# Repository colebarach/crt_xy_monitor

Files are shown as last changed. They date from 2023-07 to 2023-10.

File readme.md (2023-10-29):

# CRT Vector Display Driver

## Overview

This project outlines the design of a driver circuit for a CRT screen. The tube used in this project is a 4" magnetic coil driven screen from a GE portable TV. No information could be found online about this tube, so the pinout of it and its corresponding flyback had to be reverse engineered. 

### Notes

This repository details the design and creation of an X-Y monitor. For details on generating X-Y signals to display, see the sister repository (https://github.com/colebarach/lib_xy_display).

## Tube Power Supply

To power the CRT, several kilovolts must be provided to accelerate the electron beam. This is typically provided by a flyback transformer. As mentioned previously, the tube used in this project came with a transformer.
To drive the flyback transformer, a sinusoidal AC signal is approximated using a square wave generated with a monostable multivibrator.
This approach is not efficient, but it is sufficient for the size of the tube and is relatively simple.

## Circuit Schematic
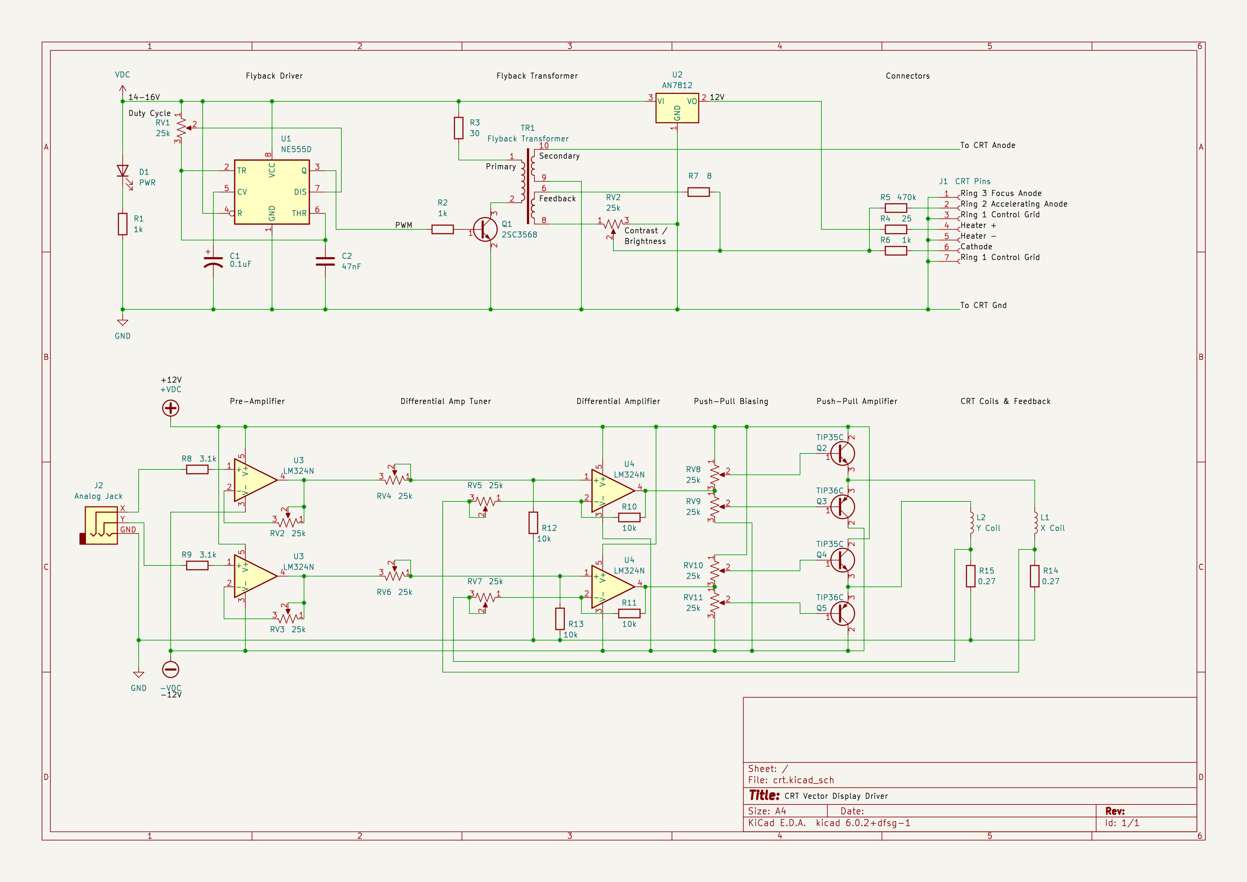
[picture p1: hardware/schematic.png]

*Datasheets are provided in the datasheets directory.

## Coil Driver
The coils of the CRT are responsible for the rendering.
Two signals are input to the driver, being the X and Y position of the beam, which range from -5V to 5V.
Each signal first runs through a pre-amplifier, which accomodates for the variety of signal generators used in testing.
The signals then go through negative feedback, unity gain, differential amplifiers, which receives feedback from the actual position of the beam.
Finally a set of push-pull amplifiers drives the high current required by the coils of the tube.
The position of the beam is proportional to the current drawn by each coil, but not the voltage of the coil. To accomodate for the effects of parasitic capacitance, this current is measured via a shunt resistor.
The voltage of this, proportional to the current, is used as the negative feedback for the differential amplifiers of the system.
- This design is derivative of one detailed in "The Secret Life of XY Monitors" by Jed Margolin. For a more in-depth explanation of its operation visit his work linked in the references.

## Generating X-Y Signals
Any device capable of generating two analog signals can be used with this driver, as long as the pre-amplifiers are capable of bringing it within range. The most accessible device which can do this is the audio output of a computer. The right and left channels can be mapped to X-Y (or vice versa) and images can be drawn. A tool known as "Rabiscoscopio" has been designed for this exact purpose (see Alex Porto's link below). Using Rabiscoscopio svg files can be converted to audio files and played. Several demos are also available for quick testing.

## References
- Cathode-Ray Tubes - Chuck DeVere (https://openlibrary.org/books/OL17878693M/Cathode-ray_tubes)
- Flyback Transformer Design Considerations for Efficiency and EMI - Texas Instruments (https://www.ti.com/seclit/ml/slup338/slup338.pdf)
- Operation of a Cathode Ray Tube - Georgia Institute of Technology
- Cathode Ray Tube Displays - MIT Radiation Laboratory (https://www.bunkerofdoom.com/lit/mitser/PREF22.PDF)
- Some Vector Generating Techniques for Cathode Ray Tube Display Systems - NASA Godoard Space Flight Center (https://ntrs.nasa.gov/api/citations/19670021973/downloads/19670021973.pdf)
- CRT Electron Beam Deflection with Microcontroller - Bob's Projects (https://bobparadiso.com/2015/04/13/crt-electron-beam-deflection-w-microcontroller/)
- The Secret Life of XY Monitors - Jed Margolin (http://www.jmargolin.com/xy/xymon.htm)
- Atari 19 and 25 Inch Color X-Y Display - Atari (https://www.andysarcade.net/personal/manualsother.htm)
- Wells-Gardner Quadrascan Color X-Y Display Service Manual - Atari - (https://archive.org/details/ArcadeGameManualTm183-2)
- Response of Electromagnetic Deflection for CRT Display - Hiroya Sano & Yoshihiro Tanada (https://core.ac.uk/download/pdf/12528813.pdf)
- Rabiscoscopio 2 - Alex Porto (https://dalpix.com/oscilloscope-drawing-everyone)
- Flyback Driver #1: Single Transistor Driver - Jozef Bogin Jr (http://boginjr.com/electronics/hv/flyback-driver-1/)
- Flyback Driver #2: NE555 Quasi-Resonant (http://boginjr.com/electronics/hv/flyback-driver-2/)
- Things to do: Drive a CRT - Jochen Kronjaeger (http://www.kronjaeger.com/hv-old/hv/do/crt/index.html)

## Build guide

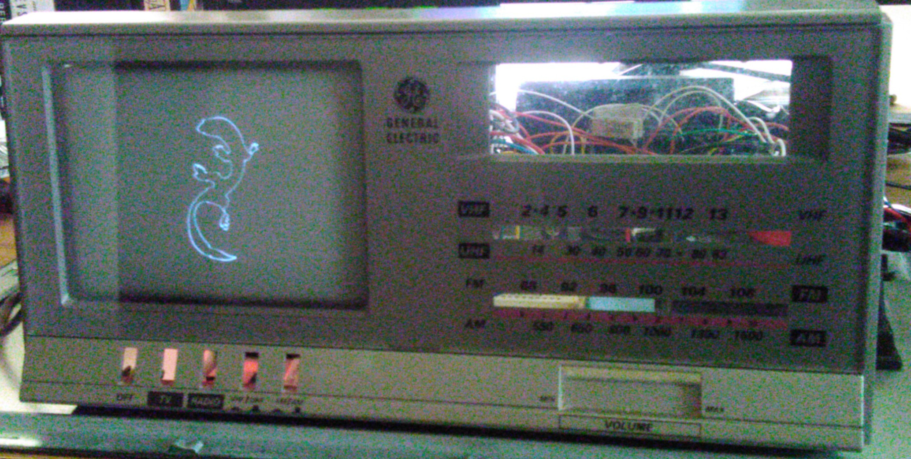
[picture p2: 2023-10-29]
tests/23.07.15 - Hardware Setup Screen.jpg

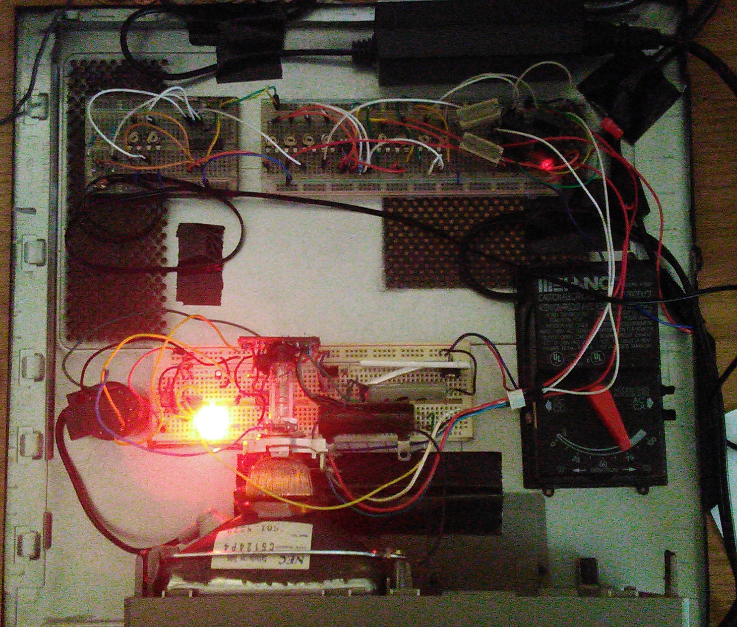
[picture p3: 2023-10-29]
tests/23.07.15 - Hardware Setup Top.jpg

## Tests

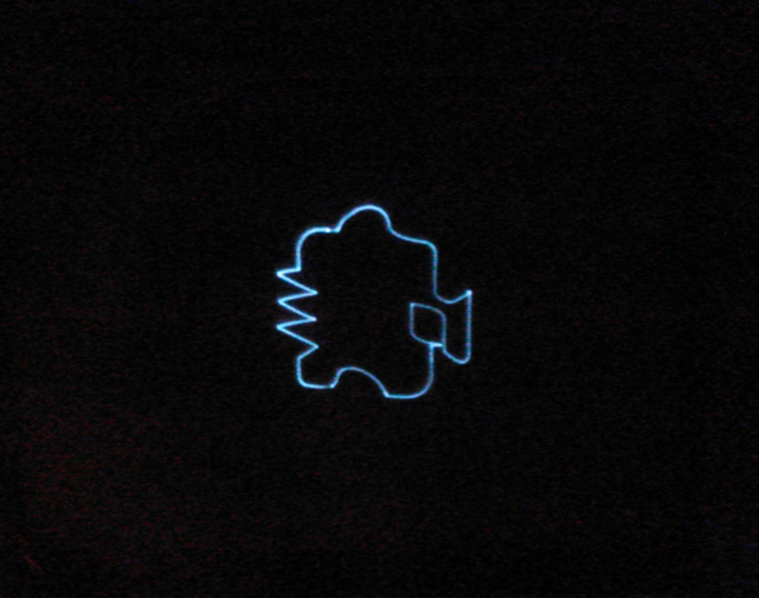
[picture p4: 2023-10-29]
tests/23.07.15 - Result Noisebridge.jpeg

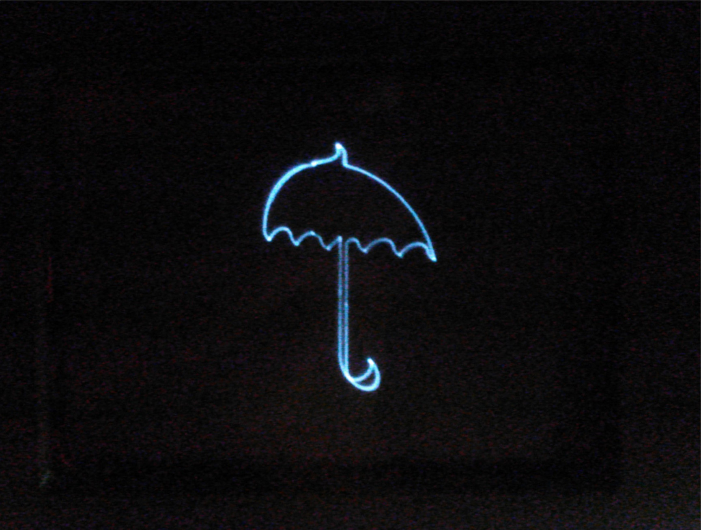
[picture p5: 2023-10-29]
tests/23.07.15 - Result Garoa.jpeg

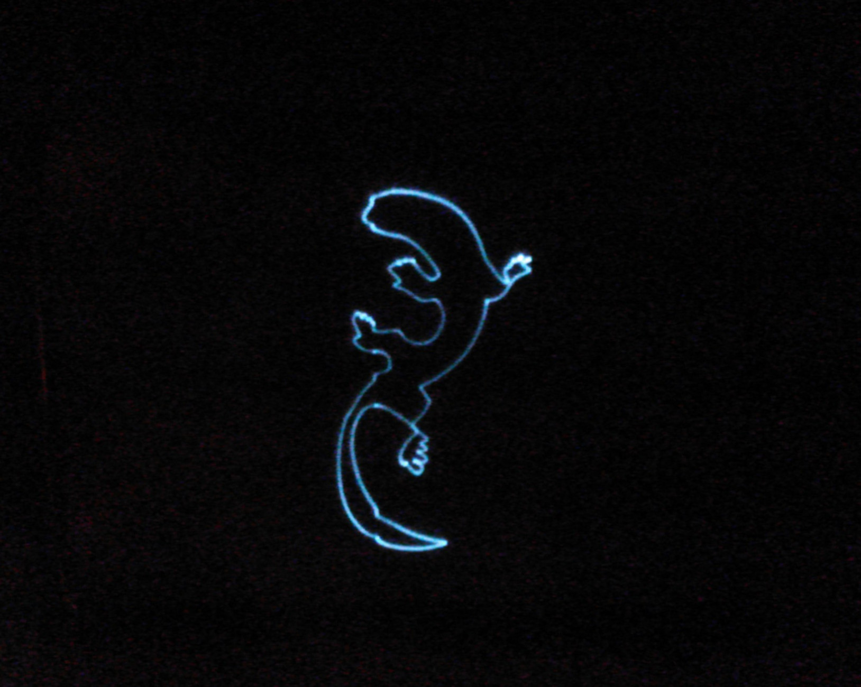
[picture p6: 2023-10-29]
tests/23.07.15 - Result Calango.jpeg

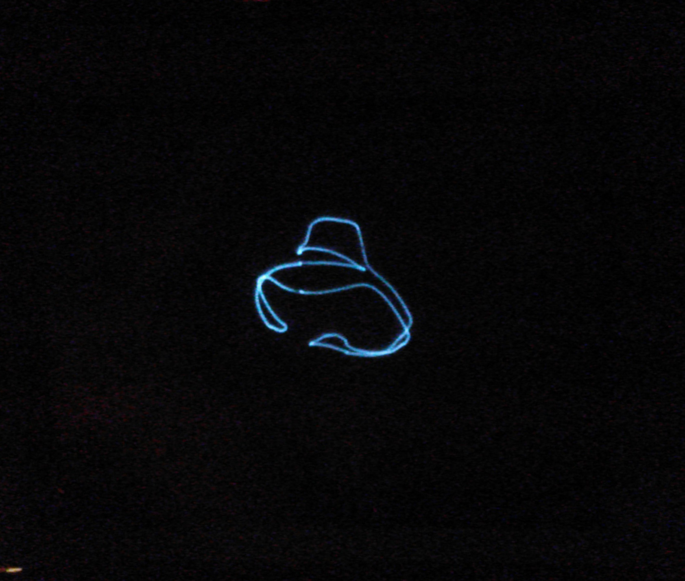
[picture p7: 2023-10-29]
tests/23.07.15 - Result Dumont.jpeg

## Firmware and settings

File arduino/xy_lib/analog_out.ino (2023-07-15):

#include <TimerOne.h>

const int xPin = 9;
const int yPin = 10;

int period = 64;

// 256
int distanceLookup[] =
{
  0,
  1501
};

void setup()
{
  Timer1.initialize(period);
  
  pinMode(xPin, OUTPUT);
  pinMode(yPin, OUTPUT);
}

void loop()
{
  demoSizeDelay2();
  
//  drawFontA(0, 0);
//  drawFontB(12, 0);
//  drawFontC(24, 0);
//  drawFontD(36, 0);
//  drawFontE(48, 0);
//  drawFontF(60, 0);
}

void drawFontNull(int x, int y)
{
  drawVector(x,   y);
  drawVector(x+8, y);
  drawVector(x+8, y+12);
  drawVector(x,   y+12);
  
  drawVector(x,   y);
  drawVector(x+8, y);
}

void drawFontA(int x, int y)
{
  drawVector(x,   y);
  drawVector(x+2, y+6);
  drawVector(x+6, y+6);
  drawVector(x+2, y+6);
  drawVector(x+4, y+12);
  drawVector(x+8, y);
}

void drawFontB(int x, int y)
{

  drawVector(x,   y);
  drawVector(x,   y+12);
  drawVector(x+8, y+12);
  drawVector(x+8, y+8);
  drawVector(x+6, y+6);
  drawVector(x,   y+6);
  drawVector(x+6, y+6);
  drawVector(x+8, y+4);
  drawVector(x+8, y);
  drawVector(x,   y);
}

void drawFontC(int x, int y)
{
  drawVector(x+8, y);
  drawVector(x+2, y);
  drawVector(x,   y+2);
  drawVector(x,   y+10);
  drawVector(x+2, y+12);
  drawVector(x+8, y+12);
}

void drawFontD(int x, int y)
{
  drawVector(x,   y);
  drawVector(x,   y+12);
  drawVector(x+6, y+12);
  drawVector(x+8, y+10);
  drawVector(x+8, y+2);
  drawVector(x+6, y);
  drawVector(x,   y);
}

void drawFontE(int x, int y)
{
  drawVector(x+8, y);
  drawVector(x,   y);
  drawVector(x,   y+6);
  drawVector(x+8, y+6);
  drawVector(x,   y+6);
  drawVector(x,   y+12);
  drawVector(x+8, y+12);
}

void drawFontF(int x, int y)
{
  drawVector(x,   y);
  drawVector(x,   y+6);
  drawVector(x+8, y+6);
  drawVector(x,   y+6);
  drawVector(x,   y+12);
  drawVector(x+8, y+12);
}

void drawPoint(int x, int y)
{
  Timer1.pwm(xPin, x, period);
  Timer1.pwm(yPin, y, period);
}

void drawVector(int x, int y)
{
  int distance = x;

  if(y > x) distance = y;

  delayMicroseconds(3200);

  Timer1.pwm(xPin, x, period);
  Timer1.pwm(yPin, y, period);
}

void demoSizeDelay()
{
  int step = 32;
  
  for(int x = step; x < 256; x += step)
  {
    drawVector(x,0);
    drawVector(x,x);
    drawVector(0,x);

    x += step;
    
    drawVector(0,x);
    drawVector(x,x);
    drawVector(x,0);
  }
}

void demoSizeDelay2()
{
  int step = 64;
  
  for(int x = step; x < 255; x += step)
  {
    drawVector(255-x,255);
    drawVector(255-x,255-x);
    drawVector(255,  255-x);

    x += step;
    
    drawVector(255,  255-x);
    drawVector(255-x,255-x);
    drawVector(255-x,255);
  }
}

void demoHilbertCurve(int depth)
{
  
}

void drawHilbertCurve(int x, int y, int rotation, int symmetry, int depth)
{
  if(depth == 0) return;
  
  // Scale LUT (1 / (2^x - 1))
  int scale = 255;
  if     (depth == 2) scale = 85;
  else if(depth == 3) scale = 36;
  else if(depth == 4) scale = 17;
  else if(depth == 5) scale = 8;
  else if(depth == 6) scale = 4;
  else if(depth == 7) scale = 2;
  else if(depth == 8) scale = 1;

  if(symmetry == 0)
  {
    if(rotation == 0)
    {
      drawHilbertCurve(x, y, 1, 1, depth-1);
      
      drawVector(x + scale + subscale, y);
      
      drawHilbertCurve(x, y, 0, 0, depth-1);
      
      drawVector(x + scale + subscale, y + scale + subscale);
      
      drawHilbertCurve(x, y + scale, 0, 0, depth-1);
      
      drawVector(x, y);
      
      drawHilbertCurve(x, y, 3, 1, depth-1);
    }
    else if(rotation == 1)
    {
      
    }
    else if(rotation == 2)
    {
      
    }
    else if(rotation == 3)
    {
      
    } 
  }
  else
  {
    if(rotation == 0)
    {
      
    }
    else if(rotation == 1)
    {
      
    }
    else if(rotation == 2)
    {
      
    }
    else if(rotation == 3)
    {
      
    }
  }
}

//
//void demoStar()
//{
//  Timer1.pwm(xPin, 127, period);
//  Timer1.pwm(yPin, 127, period);
//
//  delayMicroseconds(drawDelay);
//
//  Timer1.pwm(xPin, 255, period);
//  Timer1.pwm(yPin, 127, period);
//
//  delayMicroseconds(drawDelay);
//
//  Timer1.pwm(xPin, 127, period);
//  Timer1.pwm(yPin, 127, period);
//
//  delayMicroseconds(drawDelay);
//
//  Timer1.pwm(xPin, 225, period);
//  Timer1.pwm(yPin, 209, period);
//
//  delayMicroseconds(drawDelay);
//
//  Timer1.pwm(xPin, 127, period);
//  Timer1.pwm(yPin, 127, period);
//
//  delayMicroseconds(drawDelay);
//
//  Timer1.pwm(xPin, 149, period);
//  Timer1.pwm(yPin, 253, period);
//
//  delayMicroseconds(drawDelay);
//
//  Timer1.pwm(xPin, 127, period);
//  Timer1.pwm(yPin, 127, period);
//
//  delayMicroseconds(drawDelay);
//
//  Timer1.pwm(xPin, 63, period);
//  Timer1.pwm(yPin, 237, period);
//
//  delayMicroseconds(drawDelay);
//
//  Timer1.pwm(xPin, 127, period);
//  Timer1.pwm(yPin, 127, period);
//
//  delayMicroseconds(drawDelay);
//
//  Timer1.pwm(xPin, 7, period);
//  Timer1.pwm(yPin, 171, period);
//
//  delayMicroseconds(drawDelay);
//
//  Timer1.pwm(xPin, 127, period);
//  Timer1.pwm(yPin, 127, period);
//
//  delayMicroseconds(drawDelay);
//
//  Timer1.pwm(xPin, 7, period);
//  Timer1.pwm(yPin, 83, period);
//
//  delayMicroseconds(drawDelay);
//
//  Timer1.pwm(xPin, 127, period);
//  Timer1.pwm(yPin, 127, period);
//
//  delayMicroseconds(drawDelay);
//
//  Timer1.pwm(xPin, 63, period);
//  Timer1.pwm(yPin, 17, period);
//
//  delayMicroseconds(drawDelay);
//
//  Timer1.pwm(xPin, 127, period);
//  Timer1.pwm(yPin, 127, period);
//
//  delayMicroseconds(drawDelay);
//
//  Timer1.pwm(xPin, 149, period);
//  Timer1.pwm(yPin, 1, period);
//
//  delayMicroseconds(drawDelay);
//
//  Timer1.pwm(xPin, 127, period);
//  Timer1.pwm(yPin, 127, period);
//
//  delayMicroseconds(drawDelay);
//
//  Timer1.pwm(xPin, 225, period);
//  Timer1.pwm(yPin, 45, period);
//
//  delayMicroseconds(drawDelay);
//}
//
//void demoSquare()
//{
//  Timer1.pwm(xPin, 0, period);
//  Timer1.pwm(yPin, 0, period);
//
//  delayMicroseconds(drawDelay);
//
//  Timer1.pwm(xPin, 255, period);
//  Timer1.pwm(yPin, 0,   period);
//
//  delayMicroseconds(drawDelay);
//
//  Timer1.pwm(xPin, 255, period);
//  Timer1.pwm(yPin, 255, period);
//
//  delayMicroseconds(drawDelay);
//  
//  Timer1.pwm(xPin, 0,   period);
//  Timer1.pwm(yPin, 255, period);
//
//  delayMicroseconds(drawDelay);
//}
//
//void demoDiamond()
//{
//  Timer1.pwm(xPin, 128, period);
//  Timer1.pwm(yPin, 0,   period);
//
//  delayMicroseconds(drawDelay);
//  
//  Timer1.pwm(xPin, 255, period);
//  Timer1.pwm(yPin, 128, period);
//
//  delayMicroseconds(drawDelay);
//
//  Timer1.pwm(xPin, 128, period);
//  Timer1.pwm(yPin, 255, period);
//
//  delayMicroseconds(drawDelay);
//
//  Timer1.pwm(xPin, 0,   period);
//  Timer1.pwm(yPin, 128, period);
//
//  delayMicroseconds(drawDelay);
//}

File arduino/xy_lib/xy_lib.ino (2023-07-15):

//// CRT Driver
////   Author  - Cole Barach
////   Created - 22.06.18
////   Updated - 22.07.16
//
//// Libraries
//#include <TimerOne.h>
//
//// Pin Assignments
//  // Output
//    const int horizontalPwmPin      = 9;
//    const int horizontalPolarityPin = 7;
//    const int verticalPwmPin        = 10;
//    const int verticalPolarityPin   = 8;
//  // Input
//    const int potentiometerPin      = A0;
//    const int buttonPin             = 3;
//
//// Control Variables
//  // Potentiometer
//    long frequencyMax = 262144;
//    long frequencyMin = 0;
//    long frequencyDelta;
//    int  frequencyStep;
//    int  period = 16;
//    bool startUp = true;
//  //Cursor
//    int xCursor;
//    int yCursor;
//
//void setup() {
//  Serial.begin(9600);
//  Timer1.initialize(period);
//  pinMode(horizontalPwmPin,      OUTPUT);
//  pinMode(horizontalPolarityPin, OUTPUT);
//  pinMode(verticalPwmPin,        OUTPUT);
//  pinMode(verticalPolarityPin,   OUTPUT);
//  frequencyDelta = frequencyMax-frequencyMin;
//  frequencyStep  = frequencyDelta/1024;
//}
//
//void loop() {
////  DemoGrid();
//  DemoQuarterGrid();
////  int fontSize = 32;
////  JumpCursor(-256,512);
////  FontA(fontSize);
////  FontB(fontSize);
////  FontC(fontSize);
////  JumpCursor(-256,0);
////  FontD(fontSize);
////  FontE(fontSize);
////  FontF(fontSize);
//}
//
//// --------------------------------------------------------------------------------------Cursor
//void WriteCursor(int x, int y) {
//  SetFrequency(); //Temporary
//  xCursor = x;
//  yCursor = y;
//  digitalWrite(horizontalPolarityPin,GetPolarity(x));
//  digitalWrite(verticalPolarityPin,  GetPolarity(y));
//  Timer1.pwm(horizontalPwmPin,abs(x),period);
//  Timer1.pwm(verticalPwmPin,  abs(y),period);
//  delayMicroseconds(32);
//  //PrintCursor();
//}
//void StepCursor(int x, int y) {
//  WriteCursor(xCursor+x, yCursor+y);
//}
//void DelayCursor() {
//  StepCursor(0,0);
//  delayMicroseconds(128);
//}
//void JumpCursor(int x, int y) {
//  WriteCursor(x,y);
//  DelayCursor();
//}
//void JumpLocalCursor(int x, int y) {
//  JumpCursor(xCursor + x, yCursor + y);
//}
//void PrintCursor() {
//  Serial.println("");
//  Serial.print(xCursor);
//  Serial.print("x - ");
//  Serial.print(yCursor);
//  Serial.print("y");
//}
//
//// --------------------------------------------------------------------------------------Primatives
//void DrawPoint(int iterations) {
//  for(int n = 0; n < iterations; n++) {
//    DelayCursor();
//  }
//}
//void DrawVector(int xStep, int yStep, int iterations) {
//  for(int n = 0; n < iterations; n++) {
//    StepCursor(xStep,yStep);
//  }
//}
//void DrawRectangle(int xStep, int yStep, int xIterations, int yIterations) {
//  DrawVector( xStep, 0,     xIterations);
//  DrawVector( 0,     yStep, yIterations);
//  DrawVector(-xStep, 0,     xIterations);
//  DrawVector( 0,    -yStep, yIterations);
//}
//void DrawArc(float theta, int radius, float thetaStep, int iterations) {
//  int xPrime = cos(theta)*radius;
//  int yPrime = sin(theta)*radius;
//  for(int n = 0; n < iterations; n++) {
//    theta += thetaStep;
//    int x = cos(theta)*radius;
//    int y = sin(theta)*radius;
//    StepCursor(x-xPrime,y-yPrime);
//    xPrime = x;
//    yPrime = y;
//  }
//}
//// --------------------------------------------------------------------------------------Font
//void FontBlock(int scale) {
//  DrawVector( 0,-12,scale);
//  DrawVector( 8, 0, scale);
//  DrawVector( 0, 12,scale);
//  DrawVector(-8, 0, scale);
//  JumpLocalCursor(8*scale,0);
//}
//void FontSpace(int scale) {
//  JumpLocalCursor(8*scale,0);
//}
//void FontA(int scale) {
//  JumpLocalCursor(0,-12*scale);
//  DrawVector( 4, 12,scale);
//  DrawVector( 4,-12,scale);
//  JumpLocalCursor(-6*scale,6*scale);
//  DrawVector( 4,  0,scale);
//  JumpLocalCursor(2*scale,6*scale);
//}
//void FontB(int scale) {
//  DrawVector( 0,-12,scale);
//  DrawVector( 3, 3, scale);
//  DrawVector(-3, 3, scale);
//  DrawVector( 3, 3, scale);
//  DrawVector(-3, 3, scale);
//  JumpLocalCursor(8*scale,0);
//}
//void FontC(int scale) {
//  JumpLocalCursor(6*scale,-12*scale);
//  DrawVector(-6, 6,scale);
//  DrawVector( 6, 6,scale);
//  JumpLocalCursor(2*scale,0);
//}
//void FontD(int scale) {
//  DrawVector( 0,-12,scale);
//  DrawVector( 6, 6, scale);
//  DrawVector(-6, 6, scale);
//  JumpLocalCursor(8*scale,0);
//}
//void FontE(int scale) {
//  DrawVector( 0,-12,scale);
//  DrawVector( 6, 0, scale);
//  JumpLocalCursor(-6*scale,6*scale);
//  DrawVector( 6, 0, scale);
//  JumpLocalCursor(-6*scale,6*scale);
//  DrawVector( 6, 0, scale);
//  JumpLocalCursor(2*scale,0);
//}
//void FontF(int scale) {
//  JumpLocalCursor(0,-12*scale);
//  DrawVector( 0,12,scale);
//  DrawVector( 6, 0, scale);
//  JumpLocalCursor(-6*scale,-6*scale);
//  DrawVector( 6, 0, scale);
//  JumpLocalCursor(2*scale,6*scale);
//}
//
//// --------------------------------------------------------------------------------------Demos
//void DemoSquare() {
//  JumpCursor(-768,-768);
//  DrawRectangle(16,16,96,96);
//}
//void DemoDiamond() {
//  JumpCursor(-768,0);
//  DrawVector( 16,-16,48);
//  DrawVector( 16, 16,48);
//  DrawVector(-16, 16,48);
//  DrawVector(-16,-16,48);
//}
//void DemoGrid() {
//  for(int xIteration = -4; xIteration <= 4; xIteration++) {
//    int polarity = ParityToPolarity(xIteration);
//    int x = 1024*polarity;
//    int y = 256*xIteration;
//    JumpCursor(x,y);
//    DrawVector(-64*polarity,0,32);
//    DelayCursor();
//  }
//  for(int yIteration = 4; yIteration >= -4; yIteration--) {
//    int polarity = ParityToPolarity(yIteration);
//    int x = 256*yIteration;
//    int y = 1024*polarity;
//    JumpCursor(x,y);
//    DrawVector(0,-64*polarity,32);
//    DelayCursor();
//  }
//}
//void DemoQuarterGrid() {
//  for(int xIteration = 0; xIteration <= 4; xIteration++) {
//    int polarity = ParityToPolarity(xIteration);
//    int x = 1024*polarity;
//    int y = 256*xIteration;
//    JumpCursor(x,y);
//    DrawVector(-64*polarity,0,32);
//    DelayCursor();
//  }
//  for(int yIteration = 0; yIteration >= -4; yIteration--) {
//    int polarity = ParityToPolarity(yIteration);
//    int x = 256*yIteration;
//    int y = 1024*polarity;
//    JumpCursor(x,y);
//    DrawVector(0,-64*polarity,32);
//    DelayCursor();
//  }
//}
//
//// --------------------------------------------------------------------------------------Math
//bool GetPolarity(int n) {
//  return n < 0;
//}
//bool GetParity(int n) {
//  while(n < 0) {
//    n += 1024;
//  }
//  return n % 2;
//}
//int ParityToPolarity(int n) {
//  return 1 - 2*GetParity(n);
//}
//void SetFrequency() {
//  if(digitalRead(buttonPin) || startUp) {
//    startUp = false;
//    long frequency = (long)analogRead(potentiometerPin)*frequencyStep + frequencyMin;
//    period = 1000000/frequency;
//    Serial.print(frequency);
//    Serial.print("Hz - ");
//    Serial.print(period);
//    Serial.println("μs");
//  }
//}

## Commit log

2023-07-15 Updated with new hardware information, started new code for Arduino tests
    [crt.kicad_pcb, crt.kicad_sch]
2023-07-15 Added test results from 23.07.15
    [notes.kicad_sch]
2023-10-29 Renamed arduino directory
